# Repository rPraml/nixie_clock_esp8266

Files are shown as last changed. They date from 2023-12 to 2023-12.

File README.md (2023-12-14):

# Nixie Clock mit ESP 8266

Hier stelle ich mein Projekt vor, wie ich aus einem Nixie-Clock Steam Punk Bausatz und einen ESP8266 eine Nixie-Uhr gebaut habe.

## Nixie Clock Bausatz

Den Bausatz findet man auf Ali-Express oder Ebay unter `Vintage IN-12 Nixie Clock`.

Der Bausatz enthält eigentlich alles, was man zum Bau einer Uhr benötigt:
- Glaskuppel
- Hölzerne Bodenplatte
- Nixie Röhren (Achtung, es werden auch Bausätze ohne Röhren angeboten)
- Versilberte Drähte
- Alle notwendigen Bauteile wie Röhrentreiber, Spannungsregler, RTC-Chip und vorprogrammierten Controller etc.

## Modifikationen

Was mir an dem Bausatz nicht gefallen hat, war die Tatsache dass keine Röhrensockel dabei waren und der vorprogrammierte Atmel-Controller.

Deshalb habe ich entschieden, den Atmel-Controller + RTC-Chip durch einen ESP-8266 zu ersetzen und einen Röhrensockel zu drucken.

### Nixie Sockel

Dazu habe ich auf Tinkercad einen [Nixie Sockel](https://www.tinkercad.com/things/6y6FLwPQoSc-nixie-sockel) erstellt und ausgedruckt

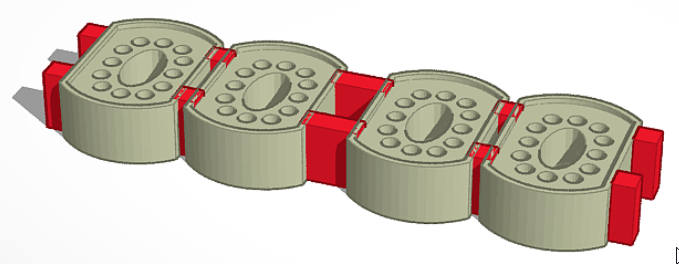
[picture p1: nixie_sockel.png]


Als Steckkontakte habe ich bei Amazon [Lötösen](https://www.amazon.de/gp/product/B07YLLM53J) bestellt.

### ESP8266

Da ich für den Atmel-Controller keine Firmware hatte, war schnell klar, dass da was selbst programmierbares her muss. Deshalb habe ich den Atmel und RTC Chip durch einen esp8266-Controller ersetzt.

Die Vorteile liegen auf der Hand:
- über den esp8266 kann die Zeit per NTP aus dem Internet geholt werden
- durch die eigene Firmware musste ich mich nicht so exakt an den Verdrahtungsplan halten:

  Bei der Verdrahtung der Schieberegister und der Röhrentreiber ging ich immer den kreuzungsfreisten Weg. So ist z.B. der Ausgang mit Segement 1 tatsächlich mit Segement 3 verbunden etc. Die Korrektur erfolgt dann (unsichtbar) in Software

- Es wurden noch weitere Spielereien implementiert, wie z.B. WS2812 RGB Leds hinter den Röhren, welche für einen blauen oder roten Glüheffekt sorgen

- Weitere Spielereien wären denkbar, z.B. Messwerte aus der Home-Automation per MQTT zu schicken

### Aufbau

Nachdem alles gründlich vermessen war und ich den Sockel ausgedruckt habe, begann ich mit dem Aufbau.

Hier habe ich darauf geachtet, die Silberdrähte möglichst exakt zu biegen und soweit wie möglich sauber zu arbeiten.

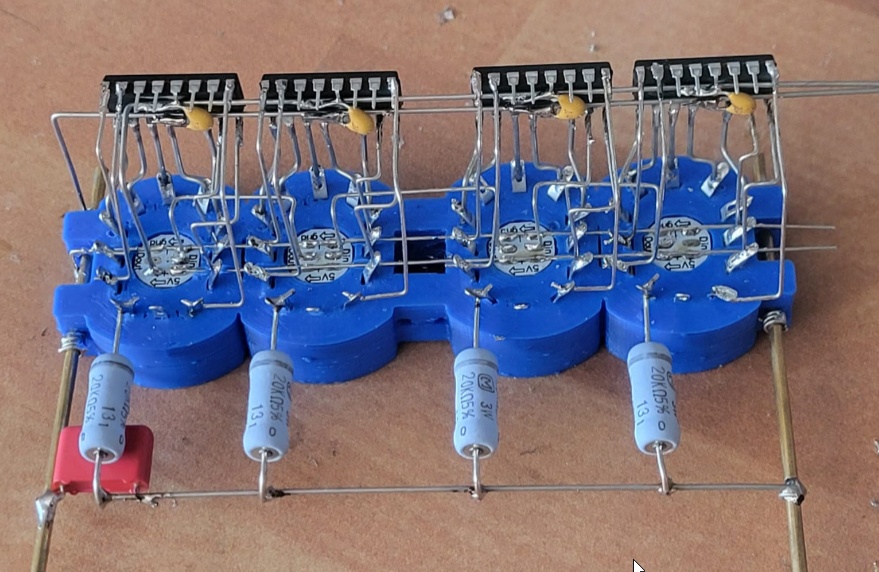
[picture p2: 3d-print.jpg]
3d-print


Dieses Bild zeigt
- 3D gedruckter Röhrensockel 
- kreuzungsfrei verbundene Röhrentreiber
- WS2812 LEDs im Röhrensockel
- unten Anodenwiderstände
- links Masse
- rechts Anodenzuleitung +180V   

### Fertig aufgebaut

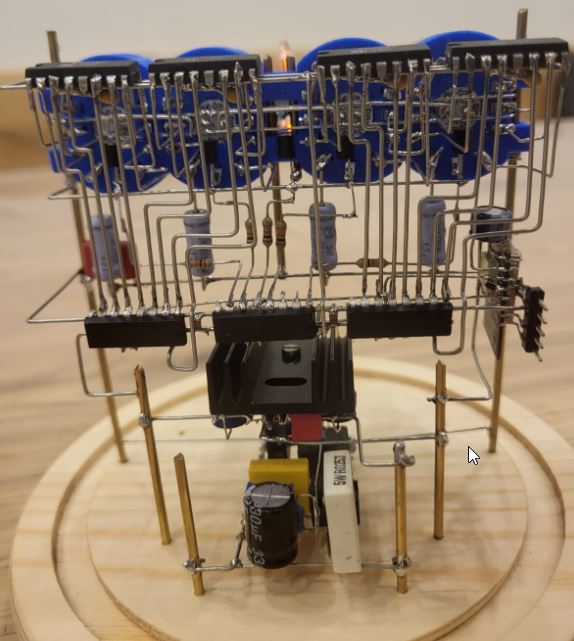
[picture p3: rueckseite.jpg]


- Rechts sieht man den ESP mit den Programmierheader.
- Unten ist das Hochvolt-Netzteil, sowie ein Spannungsregler für 5V + 3,3V
- Über die Messingdrähte wird GND, +3,3V, +5V und +180V nach oben geleitet
- Ganz hinten sieht man die 3 Schieberegister (SN74HC595N)
- Am Röhrensockel erkennt man noch ein paar Transistoren und die RGB-LEDs
- Oben befinden sich 4 russische К155ИД1 Röhrentreiber

Funktionsablauf
- Der ESP8266 steuert die Schieberegister und die RGB Leds an
- 2 der 3 Schieberegister steuern die 4 russischen К155ИД1 Röhrentreiber an
- die restlichen Ausgänge steuern die Dezimalpunkte, sowie den Doppelpunkt im Sekundentakt an
- Sobald der ESP8266 hoch fährt, holt er sich vom DHCP eine IP-Adresse und zeigt diese kurz an. Danach synchronisiert er seine interne Uhr mit einem NTP Server
- Es wird dann abwechselnd Datum und Uhrzeit angezeigt
- Ebenfalls gibt es einen Fader-Effekt, der die LEDs abwechselnd zwischen rot und blau wechseln lässt

### Weitere Bilder

**Ansicht von oben**

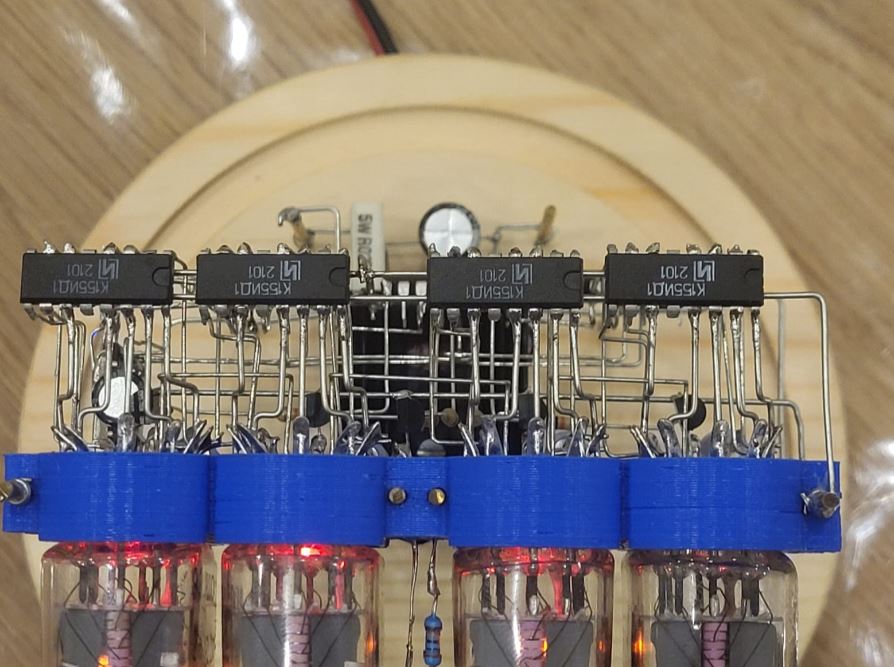
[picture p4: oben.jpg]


Hier sieht man die Röhrentreiber

----

**Ansicht von der Seite**

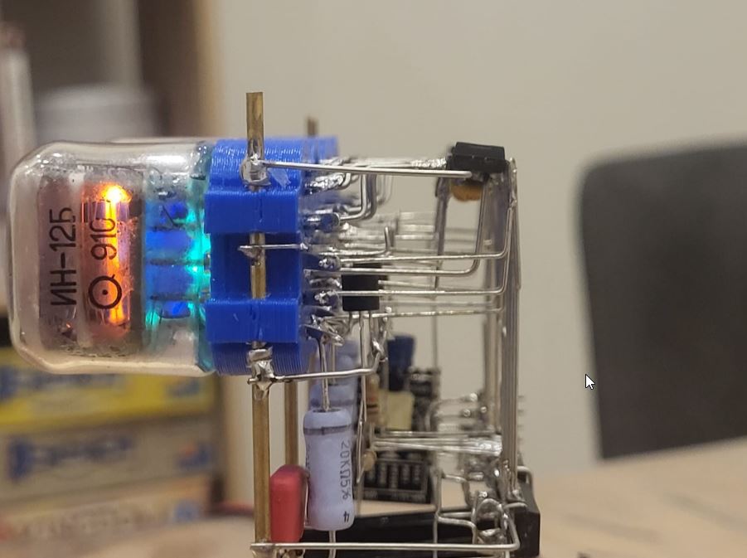
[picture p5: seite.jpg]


Hier sieht man, wie die Silberdrähte gebogen sind

----

**Anzeige des Datums**

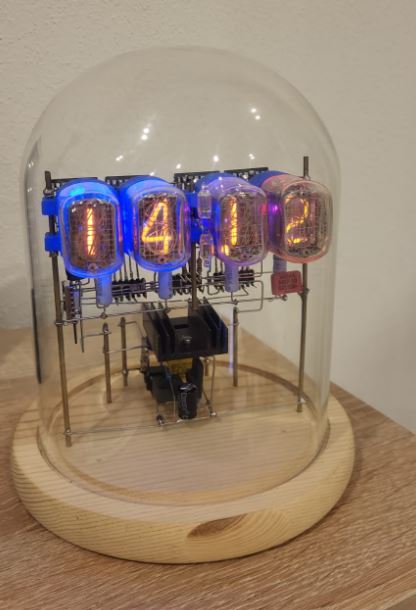
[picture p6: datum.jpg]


Angezeigt wird der 14.12

Beim Datum erscheint ein Dezimalpunkt zwischen Tag und Monat

----

**Anzeige der Uhrzeit**

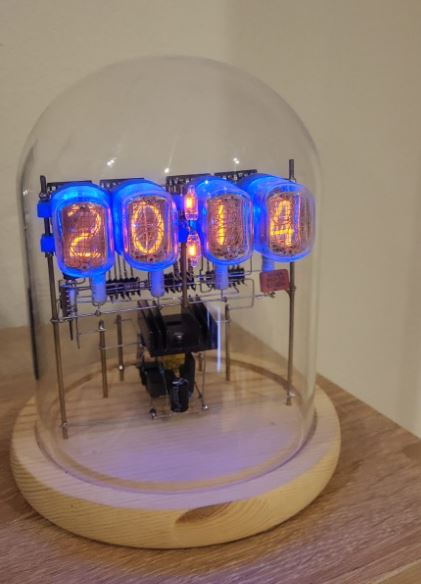
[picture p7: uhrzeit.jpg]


Angezeigt wird 20:14

Die Datums und Uhrzeitanzeige wechselt ca. alle 12 sek. Zwischen dem Wechsel gibt es einen "Rolling Number Effekt". Dabei werden kurz alle Segemente der Reihe nach angesteuert, so dass sich die Segemente freibrennen und die Röhren länger halten

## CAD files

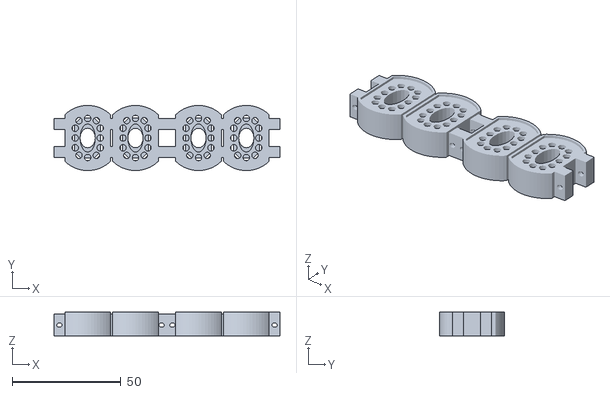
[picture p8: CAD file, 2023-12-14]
nixie_sockel.stl
104.0 x 30.0 x 11.0

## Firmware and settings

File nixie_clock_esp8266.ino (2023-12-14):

/*********
  Basic implementation of a Nixie clock. The ESP8266 drives 3 74HC595 shift registers.
  Two of them are wired to 4 russian K155ND1 nixie tube drivers. The third one is used
  to drive decimal points and the second flasher.

  For some visual effects, there are also 4 WS2812 neopixel compatible LEDs, which create a 
  color fading effect
*********/

#include <ESP8266WiFi.h>
#include <ESP8266mDNS.h>
#include <WiFiUdp.h>
#include <Adafruit_NeoPixel.h>
#include <time.h>

// define your network credentials in credentials.h
// const char* ssid = ....;
// const char* password = ....;
#include "credentials.h"

// define NTP server + timezone here
#define MY_NTP_SERVER "de.pool.ntp.org"           
#define MY_TZ "CET-1CEST,M3.5.0/02,M10.5.0/03"  

// The 74HC595 are wired to these pins
const int LATCH_PIN = 2;
const int CLOCK_PIN = 5;
const int DATA_PIN = 4;
 
const int NEOPIXEL_PIN = 15;

// const int ESP_BUILTIN_LED = 2; LED and LATCH are the same pins :(

// init the neopixel strip
Adafruit_NeoPixel strip = Adafruit_NeoPixel(4, NEOPIXEL_PIN, NEO_GRB + NEO_KHZ800);
const int NUM_LEDS = strip.numPixels();
const uint32_t RED  = strip.Color(255, 0,   0);
const uint32_t BLUE = strip.Color(0,   0,   255);
const uint32_t ORANGE = strip.Color(255,   100,  32);


class Nixie {

  /**
   * Send one bit to the shift registers
   */
  void sendBit(int bit) {
    digitalWrite(DATA_PIN, !!bit);
    digitalWrite(CLOCK_PIN, HIGH);
    delayMicroseconds(45);
    digitalWrite(CLOCK_PIN, LOW);
    delayMicroseconds(45);
  }
  
  /**
   * Send one nibble (= 4 bit) to the shift registers
   */
  void sendNibble(int nibble) {
    sendBit(nibble & 8);
    sendBit(nibble & 4);
    sendBit(nibble & 2);
    sendBit(nibble & 1);
  }

  /**
   * send one digit to the shift registers.
   * Note: The inputs and outputs of the BCD2DECIMAL converters are
   * wired "random" to have no crossings. So we must do a translation here
   */
  void sendDigit(int digit) {
    switch (digit) {
      case 0: sendNibble(12); break;
      case 1: sendNibble(2); break;
      case 2: sendNibble(10); break;
      case 3: sendNibble(11); break;
      case 4: sendNibble(3); break;
      case 5: sendNibble(1); break;
      case 6: sendNibble(9); break;
      case 7: sendNibble(8); break;
      case 8: sendNibble(0); break;
      case 9: sendNibble(4); break;
      default: sendNibble(5); break;
    }
  }

  // These are the digit values that are currently displayed
  int realDigit[4] = {-1, -1, -1, -1};

  // This is used to implement the "slot machine effect", so that 
  // all nixie digits are active from time to time, so that they do not
  // degenerate
  void decDigit(int i) {
    if (digit[i] < 0 || digit[i] > 9) {
      return;
    }
    realDigit[i]--;
    if (realDigit[i] < 0) {
      realDigit[i] = 9;
    }
  }

public:
  int synced = 0;
  int digit[4] = {-1, -1, -1, -1};
  int dot[4] = {0, 0, 0, 0};
  int colon;
  void update() {
    int i;
    for (i = 0; i < 4; i++) {
      if (digit[i] < 0 || digit[i] > 9) {
        realDigit[i] = digit[i];
      }  
    }
    // check if we are in sync
    if (synced) {
      for (i = 0; i < 4; i++) {
        if (digit[i] != realDigit[i]) {
            decDigit(0);
            decDigit(1);
            decDigit(2);
            decDigit(3);
            synced = false;
            break;
        }  
      }
    } else {
      // propagate offs
      synced = true;
      for (i = 0; i < 4; i++) {
        if (digit[i] != realDigit[i]) {
            decDigit(i);
            synced = false;
            //break;
        }  
      }
    } 
    // Send data
    sendDigit(realDigit[3]); // third 74HC595 controls minute digits
    sendDigit(realDigit[2]);
    sendBit(dot[3] || !synced);         // second 74HC595 controls decimal dots
    sendBit(dot[2] || !synced);
    sendBit(colon);
    sendBit(dot[1] || !synced);
    sendBit(0);
    sendBit(0);
    sendBit(dot[0] || !synced);
    sendBit(0);
    sendDigit(realDigit[1]); // first 74HC595 controls hour digits
    sendDigit(realDigit[0]);
    delayMicroseconds(10);
    digitalWrite(LATCH_PIN, LOW);
    delayMicroseconds(10);
    digitalWrite(LATCH_PIN, HIGH);
  }
};

Nixie nixie = Nixie();


void setup() {
  Serial.begin(115200);
  Serial.println("Booting");
  WiFi.mode(WIFI_STA);
  WiFi.begin(ssid, password);
  configTime(MY_TZ, MY_NTP_SERVER);
  while (WiFi.waitForConnectResult() != WL_CONNECTED) {
    Serial.println("Connection Failed!");
  }

  //set pins to output so you can control the shift register
  pinMode(LATCH_PIN, OUTPUT);
  pinMode(CLOCK_PIN, OUTPUT);
  pinMode(DATA_PIN, OUTPUT);
  //pinMode(ESP_BUILTIN_LED, OUTPUT);

  Serial.println("Ready");
  Serial.print("IP address: ");
  IPAddress ip = WiFi.localIP();
  Serial.println(ip);
  for (int i = 0; i < 4; i++) {
    nixie.digit[0] = ip[i] / 100;
    nixie.digit[1] = (ip[i] / 10) % 10;
    nixie.digit[2] = ip[i] % 10;
    nixie.dot[3] = true;
    do {
      nixie.update();
      delay(30);
    } while(!nixie.synced);
    delay(500);
  }
  nixie.dot[3] = false;

  
  strip.begin();
  strip.setBrightness(255);
  strip.show();
  //pinMode(ESP_BUILTIN_LED, INPUT);
}


time_t now;                         // this is the epoch
tm tm; 

void printTime() {
  time(&now);                       // read the current time
  localtime_r(&now, &tm);           // update the structure tm with the current time
  Serial.print("year:");
  Serial.print(tm.tm_year + 1900);  // years since 1900
  Serial.print("\tmonth:");
  Serial.print(tm.tm_mon + 1);      // January = 0 (!)
  Serial.print("\tday:");
  Serial.print(tm.tm_mday);         // day of month
  Serial.print("\thour:");
  Serial.print(tm.tm_hour);         // hours since midnight  0-23
  Serial.print("\tmin:");
  Serial.print(tm.tm_min);          // minutes after the hour  0-59
  Serial.print("\tsec:");
  Serial.print(tm.tm_sec);          // seconds after the minute  0-61*
  Serial.print("\twday");
  Serial.print(tm.tm_wday);         // days since Sunday 0-6
  if (tm.tm_isdst == 1)             // Daylight Saving Time flag
    Serial.print("\tDST");
  else
    Serial.print("\tstandard");
  Serial.println();
}


unsigned long previousMillis1 = 0;  // will store last time LED was updated
unsigned long previousMillis2 = 0;  // will store last time LED was updated

// constants won't change:
const long interval = 1000;  // interval at which to blink (milliseconds)

int previousSecond;
uint32_t target_color = RED;
int second_counter;
void loop() {


  time(&now);                       // read the current time
  localtime_r(&now, &tm);           // update the structure tm with the current time

  unsigned long currentMillis = millis();
  
  if (previousSecond != tm.tm_sec) {
    // save the last time you blinked the LED
    previousSecond = tm.tm_sec;
    second_counter++;
    //printTime();
    if(previousSecond % 12 < 9){
      nixie.digit[0] = tm.tm_hour / 10;
      nixie.digit[1] = tm.tm_hour % 10;
      nixie.digit[2] = tm.tm_min / 10;
      nixie.digit[3] = tm.tm_min % 10;
      nixie.dot[2] = false;
      nixie.colon = !nixie.colon;
    } else {
      tm.tm_mon++;      
      nixie.digit[0] = tm.tm_mday / 10;
      nixie.digit[1] = tm.tm_mday % 10;
      nixie.digit[2] = tm.tm_mon / 10;
      nixie.digit[3] = tm.tm_mon % 10;
      nixie.dot[2] = true;
      nixie.colon = false;
    }
    switch (second_counter % 14) {
      case 0:
        target_color = BLUE;
        break;
      case 7:
        target_color = RED;
        break;
    }
  }
  if (currentMillis - previousMillis1 > 30) {
    previousMillis1 = currentMillis;
    nixie.update();
  }

  if (currentMillis - previousMillis2 > 30) {
    previousMillis2 = currentMillis;
  
    if (strip.getPixelColor(2) == target_color) strip.setPixelColor(3,fade(strip.getPixelColor(3), strip.getPixelColor(2)));
    if (strip.getPixelColor(1) == target_color) strip.setPixelColor(2,fade(strip.getPixelColor(2), strip.getPixelColor(1)));
    if (strip.getPixelColor(0) == target_color) strip.setPixelColor(1,fade(strip.getPixelColor(1), strip.getPixelColor(0)));
    strip.setPixelColor(0,fade(strip.getPixelColor(0), target_color));
    strip.show();
  }
}

union u32_2_byte{
   uint32_t u; 
   byte b[4] ;
};

uint32_t fade(uint32_t current, uint32_t target) {
  u32_2_byte u1, u2;
  int i, j;
  u1.u = current;
  u2.u = target;

  for (i = 0; i < 4; i++) {
    for (j = 0; j < 10; j++) {
      if (u1.b[i] < u2.b[i]) u1.b[i]++;
      if (u1.b[i] > u2.b[i]) u1.b[i]--;
    }
  }
  return u1.u;
}
// Fill strip pixels one after another with a color. Strip is NOT cleared
// first; anything there will be covered pixel by pixel. Pass in color
// (as a single 'packed' 32-bit value, which you can get by calling
// strip.Color(red, green, blue) as shown in the loop() function above),
// and a delay time (in milliseconds) between pixels.
void colorWipe(uint32_t color, int wait) {
  for(int i=0; i<strip.numPixels(); i++) { // For each pixel in strip...
    strip.setPixelColor(i, color);         //  Set pixel's color (in RAM)
    strip.show();                          //  Update strip to match
    delay(wait);                           //  Pause for a moment
  }
 }
